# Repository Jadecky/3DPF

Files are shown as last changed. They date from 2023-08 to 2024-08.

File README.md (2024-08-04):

# Micron Filter

3DPF has now been retired, but V2 has been merged with the R1 Update of the Printers For Ants Micron+

This is the second itteration, that improves on some areas found from the V1 BETA

All V1 beta files and information are still available [here](https://github.com/Jadecky/3DPF/tree/main/Beta%201) for those that need them. 

## Changes iclude:
- New hex pattern for easier printing
- New Magnet system, consisting of M3x8 SHCS in the plenum, and a new push fit magnet holder in the catridge, to prevent magnets falling out due to the heat from the bed.
- Printablilty impovements
- Removed the 2x screws holding in the cartridge lid, and replaced with a chamfer to hold it in place

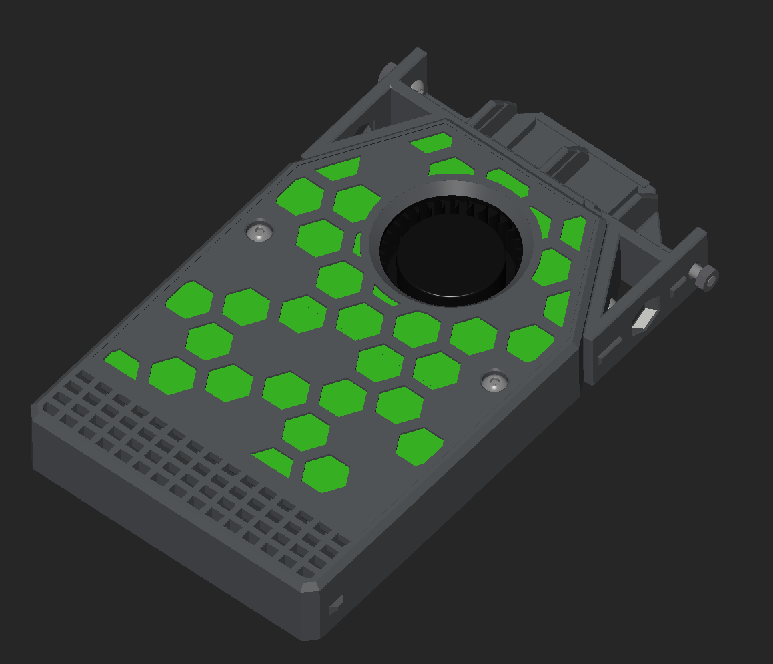
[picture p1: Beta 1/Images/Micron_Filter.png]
Micron_Filter

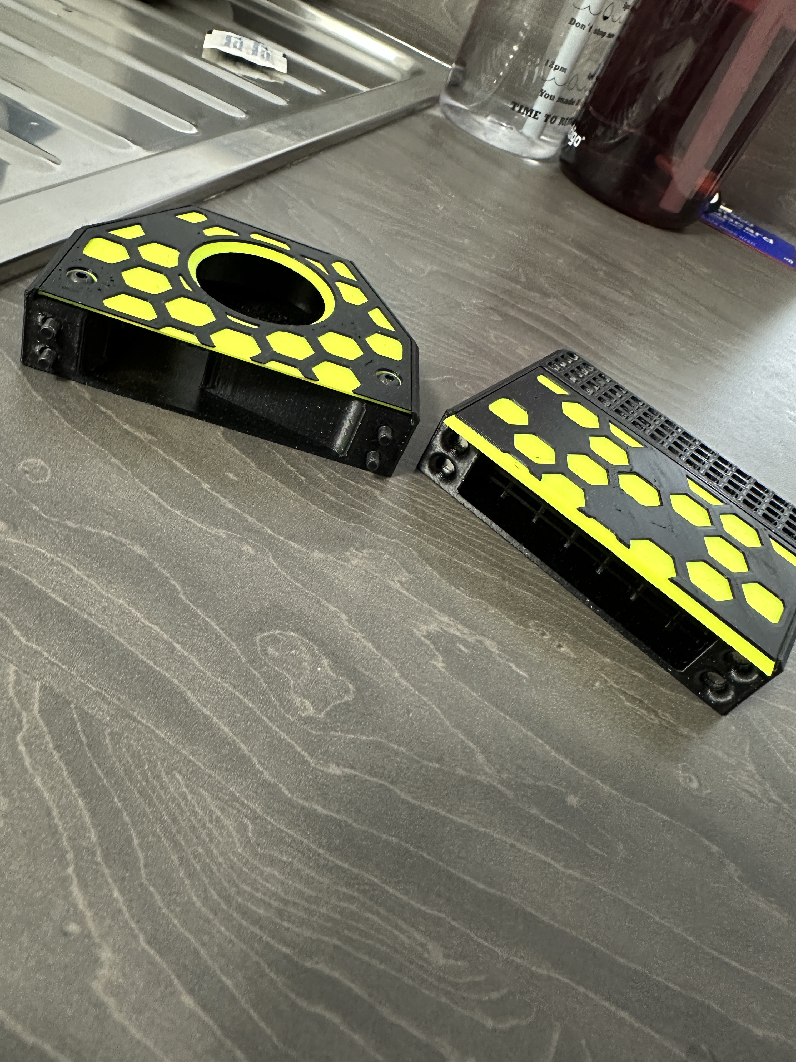
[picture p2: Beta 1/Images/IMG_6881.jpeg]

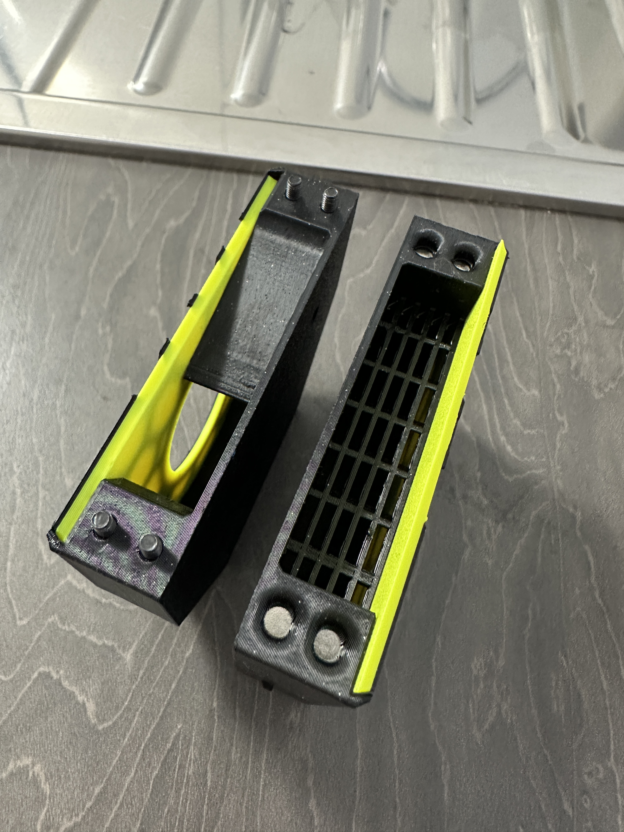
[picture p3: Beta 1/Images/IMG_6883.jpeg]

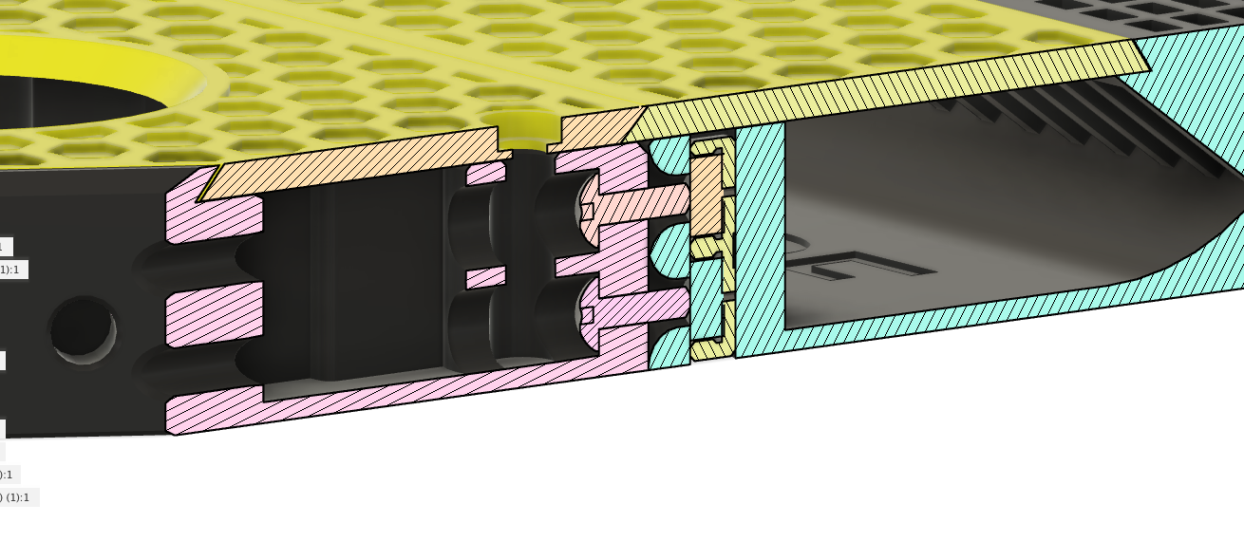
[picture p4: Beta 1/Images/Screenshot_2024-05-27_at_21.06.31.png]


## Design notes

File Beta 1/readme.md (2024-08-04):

## Legacy 3DPF V1 Information
3D Printing Filter, initially designed for PFA Micron+

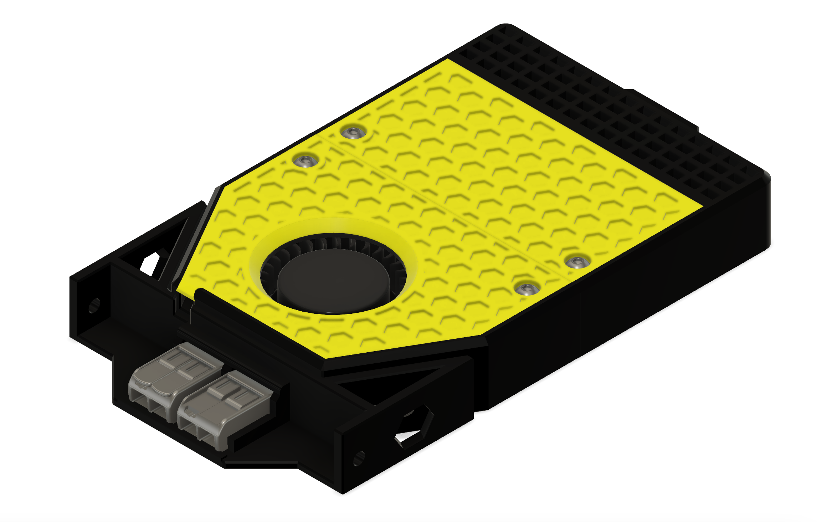
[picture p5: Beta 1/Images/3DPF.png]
3DPF


## Thank you
Equal amounts of credit should go to @staticanime for initial testing / feedback and ideas with this project. Thank you.

Also thanks to: 
- @Kyleisah for answering my 1000x CAD questions
- @.Corvid for the advice on the airflow adjustments from Test V3 to Test V4
- @clee & HartK for the naming convention style (borrowed from BFI)
- and obviously @HartK & the team for Micron+

## 3DPF
During my assembly of the Micron+ I noticed there wasn't a "made to fit" filter.

There are several very good options around:
- [The original Nevermore](https://github.com/nevermore3d/Nevermore_Micro) (Lots of good info on carbon filters on this page)
- [The ZeroFilter by @zruncho](https://github.com/zruncho3d/zerofilter)
- [The MF Nano by Maple Leaf Makers](https://github.com/MapleLeafMakers/MFNano)

These are all awesome, but are designed for other printers, so in comes the "3DPF" (3D Printing Filter):

(Name comes from me being a mechanic by trade, diesel cars have DPFs, 3D for obvious reasons, and it's pretty much a mixture of the 3x filters above)

This is my first proper CAD project, and so far it seems to be going well. It's nothing in comparison to some of the CAD geniuses in the community, but not a bad first attempt.

Current details as of Beta 1:

- 84mm (W) x 120mm (D) x 18.5mm (H)
- Uses a 5015 blower fan
- 6x3 magnets to attach the 2 bodies together
- Exhaust grill points upwards rather than to the door, with a taper to assist the air on the way out.

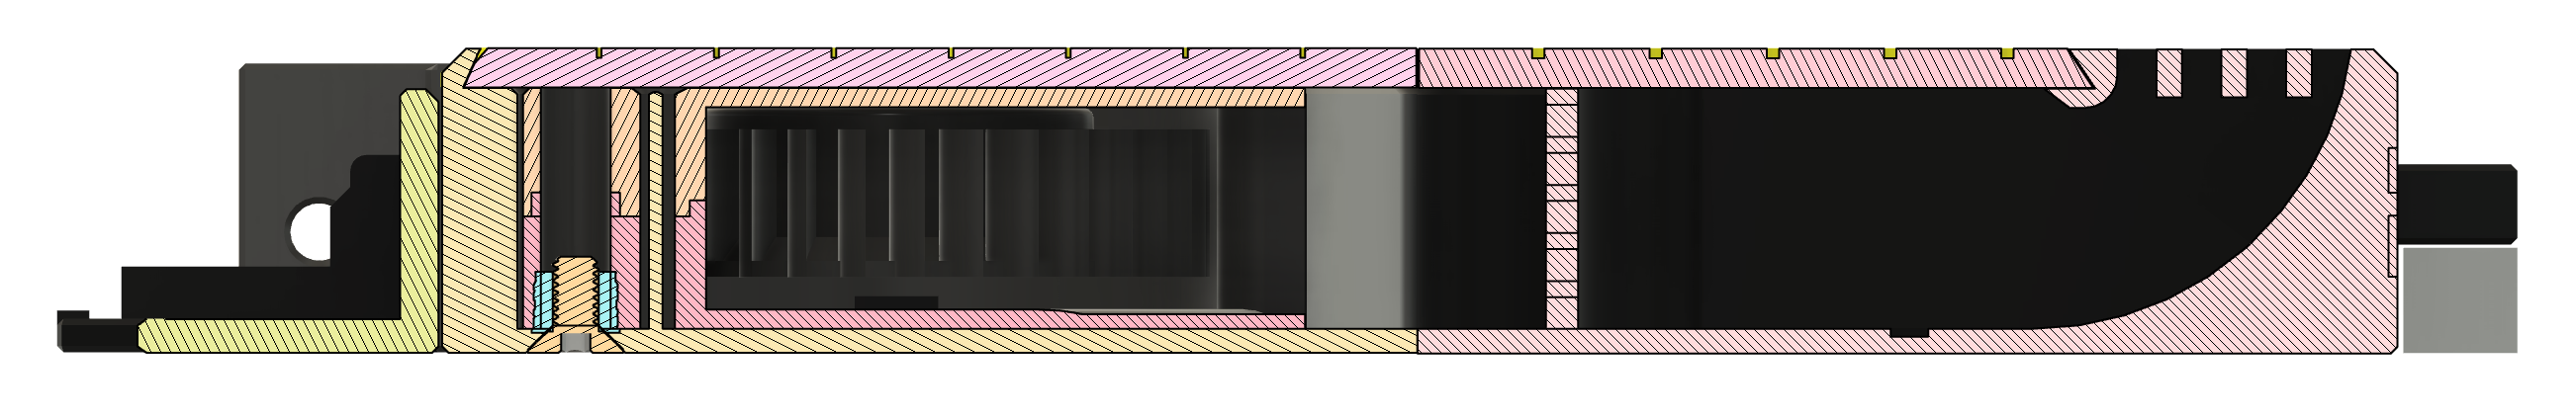
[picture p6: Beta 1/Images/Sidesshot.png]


- Current iteration has a grill with angled towers in an attempt to direct the air from the fan into the left of the cartridge.
- Wago mount / simple brackets that allow it to be slid into the extrusions from the front.
- Designed to fit under the Micron+ bed, much like the Nevermore does on a Voron V2

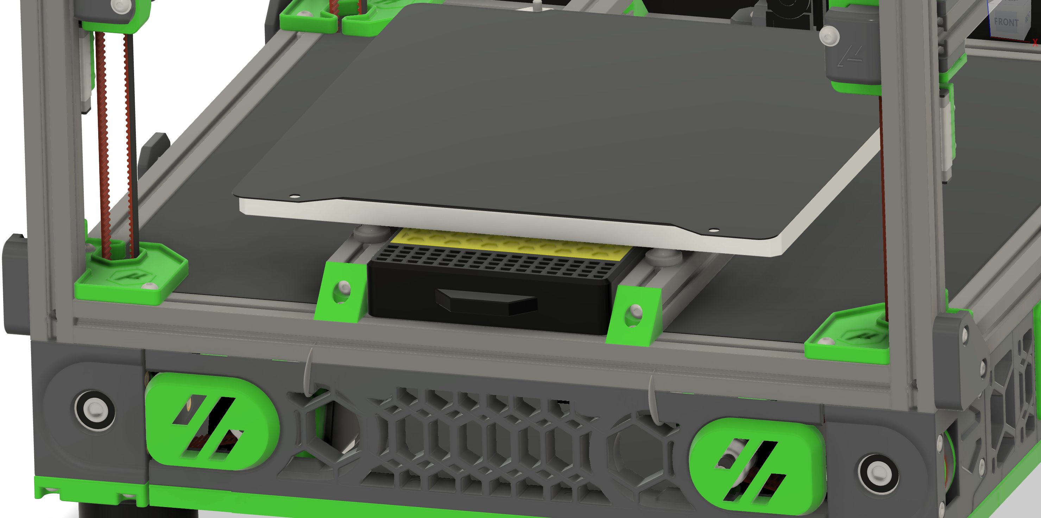
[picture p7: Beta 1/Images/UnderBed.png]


- 2x Cartridge options, one with a handle and one without.
- Handle variant includes built in, snap off supports

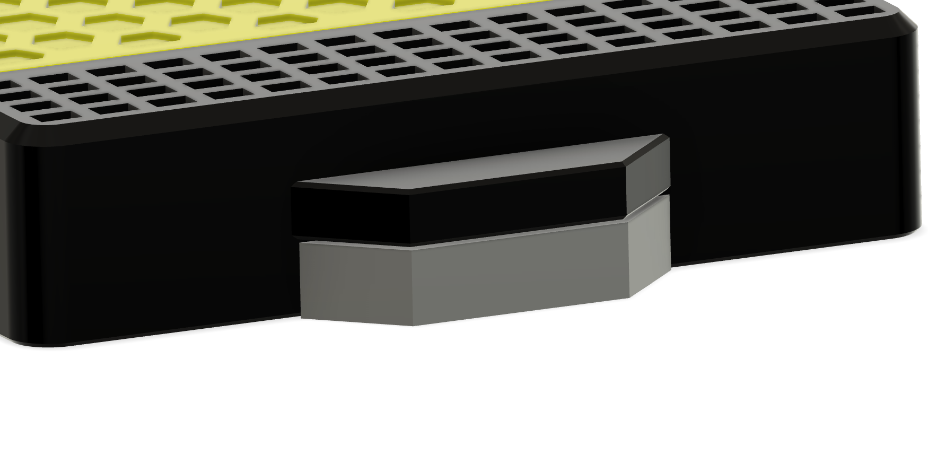
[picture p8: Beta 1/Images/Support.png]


## BOM
Qty |Part|Notes
---|----|---
8x|6x3 Magnets
8x|Voron Spec Brass Heatset Inserts|M3x5Dx4.5W
2x|M3x6 FHCS|M3x8 / M3x10 FHCS will also work
4x|M3x6 BHCS|M3x8 / M3x10 BHCS will also work for the cartridge and plenum lids
2x|M3x6 BHCS|To mount the brackets to the plenum
2x|M3x8 BHCS|To moount the brackets to the extrusions
1x|5015 Blower Fan
2x|Wago Connectors|221-412, Optional

## Printed Parts BOM
Qty|STL
---|---
1x|Plenum
1x|Cartridge [*]
1x|Cartridge_No_Text [*]
1x|Cartridge_Handle [*]
1x|Cartridge_Handle_No_Text [*]
1x|Plenum Lid
1x|Cartridge Lid
1x|Wago Mount [*]
2x|Compact Mounts (Left & Right) [*]
2x|Cartridge Removal Key

[*] Choose either/or
- "_No_Text" has no '3DPF' text on the front face of the cartridge.

## Assembly

- Insert 4x heatsets into the Cartridge and Plenum for the lid securing screws.

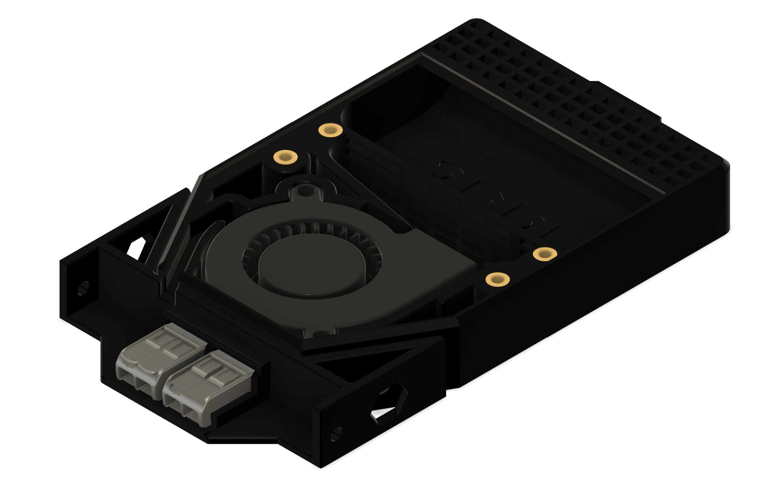
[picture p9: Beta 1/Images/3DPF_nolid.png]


- Insert 2x heatset inserts into the bottom of the screw tabs on the 5015 fan.

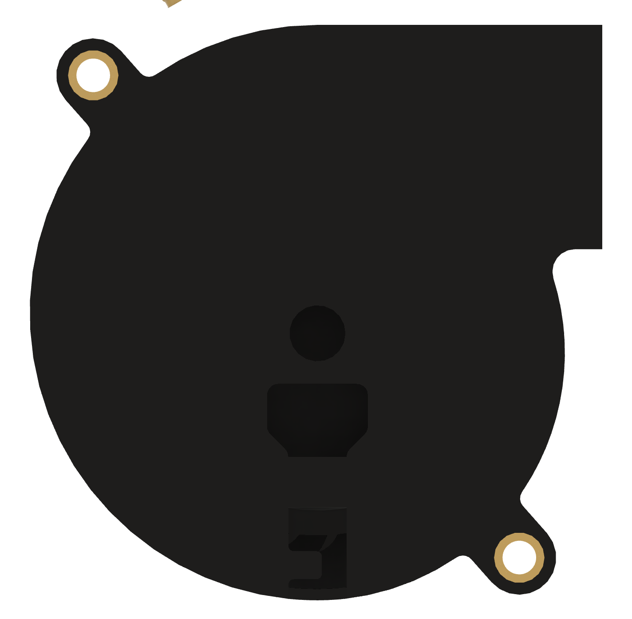
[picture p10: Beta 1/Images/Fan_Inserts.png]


- You may need to recess them 1-2 mm to allow the screws to sit correctly on the underside of the plenum.

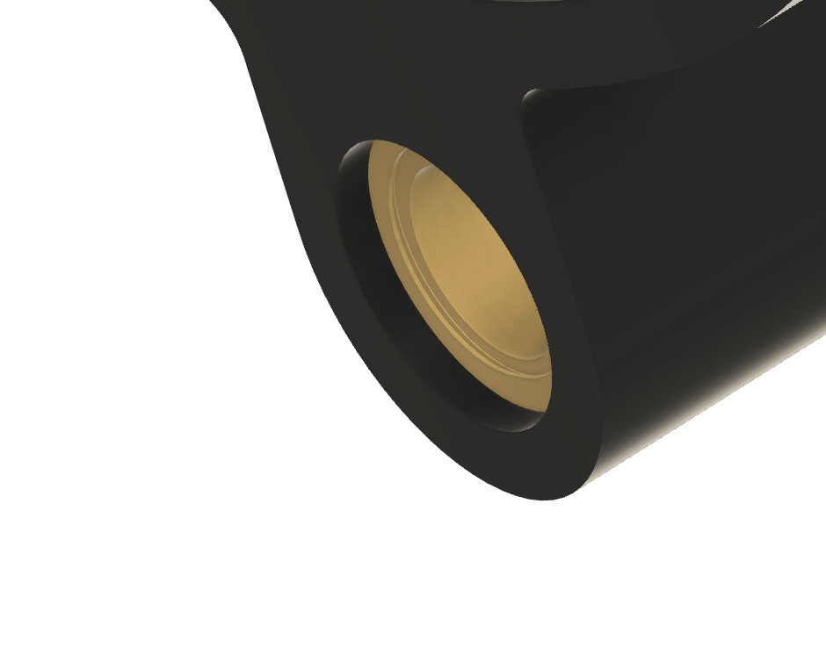
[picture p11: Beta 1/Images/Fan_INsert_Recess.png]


- Insert 2x heatsets into the 2x outside tapered edges of the plenum, where the mounting brackets will attatch. 

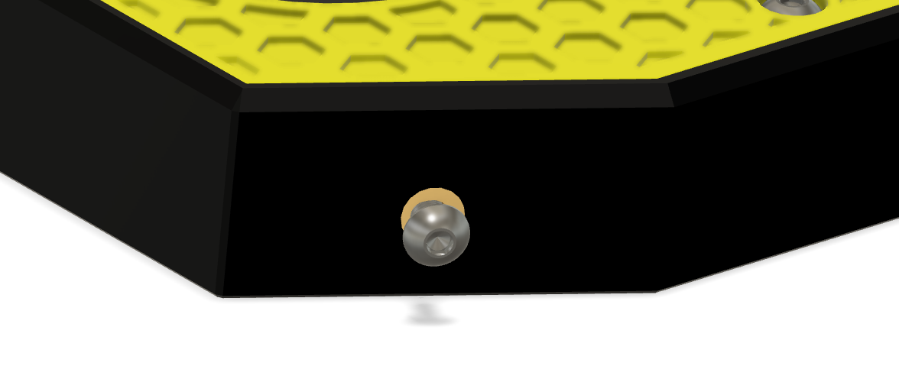
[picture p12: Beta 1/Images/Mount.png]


- Insert the fan into the plenum body routing the wire up the cable guide and out towards the back, and secure the fan with the 2x M3 FHCS from underneath the plenum.

- Attatch either the wago mount or 2x compact mounts to the plenum with M3x6 BHCS.

- Insert the 8x 6x3 Magnets into the provided holes on the mating faces of the cartridge & plenum.

- Fill cartridge with Carbon Pellets of your choosing.

- Slide the cartridge & plenum lids into place and secure with M3 BHCS.

## Cartridge Removal Key

If using the cartridge without a handle, it can be quite difficult to remove due to the 8x magnets. The removal key slots into the exhaust grill and allows you to easily pull forward on the cartridge.

You can use one in the centre, or 2x, with one on eiter outer edge.

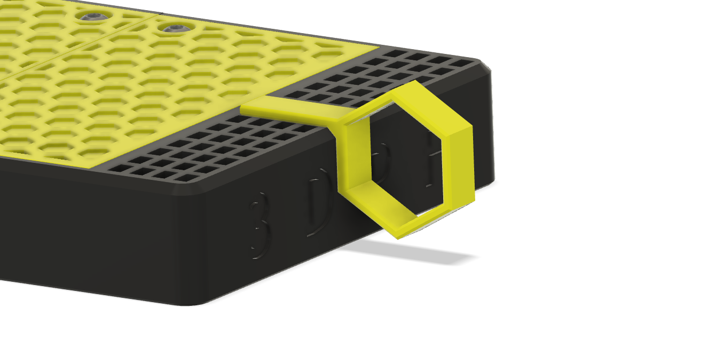
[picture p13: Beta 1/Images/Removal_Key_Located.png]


When printing, there are some tiny built in supports, shown in grey on the picture below.

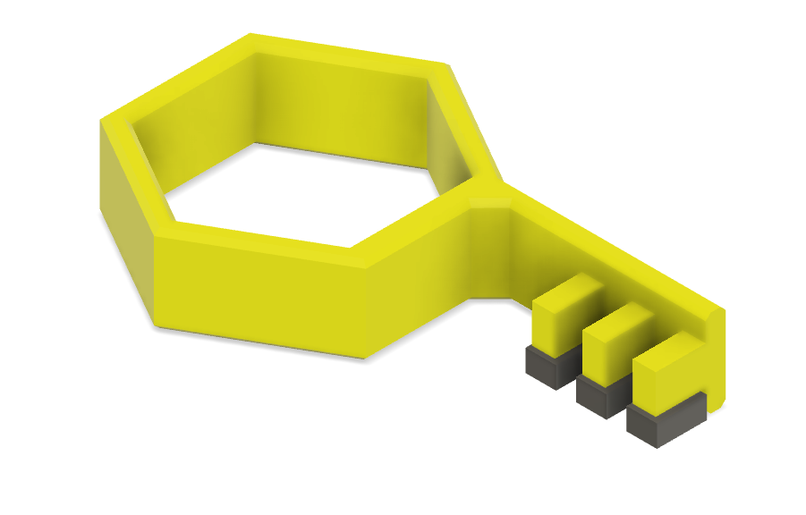
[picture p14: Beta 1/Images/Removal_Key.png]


## This filter is still in testing so any feedback/advice is much appreciated, please direct this to the [kyle_gb channel](https://discord.com/channels/825469421346226226/1132795892810907748) on the Doomcube discord.

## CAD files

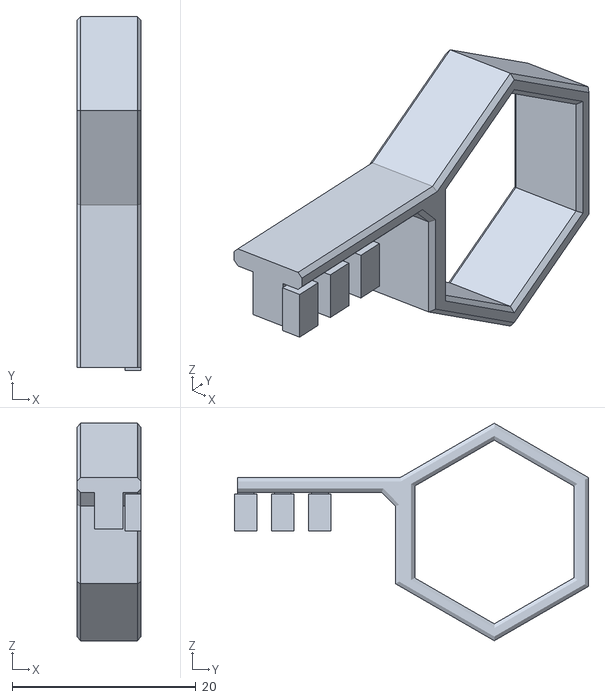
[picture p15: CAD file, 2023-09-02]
Beta 1/STLs/[a]_Cartridge_Removal_Key_x1.stl
7.00 x 38.6 x 23.7

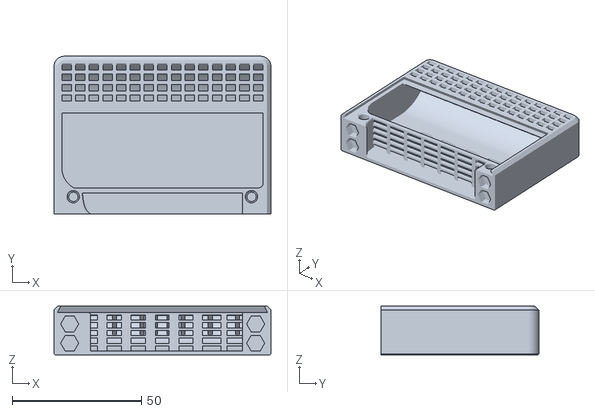
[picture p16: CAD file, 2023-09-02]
Beta 1/STLs/Cartridge.stl
84.0 x 61.0 x 19.0

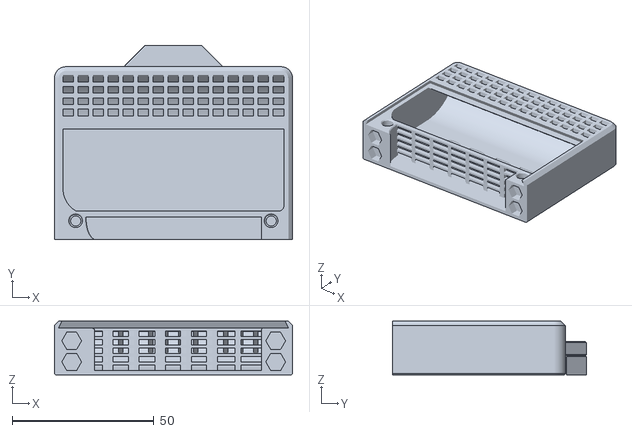
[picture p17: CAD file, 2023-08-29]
Beta 1/STLs/Cartridge_Handle_No_Text.stl
84.0 x 68.5 x 19.0

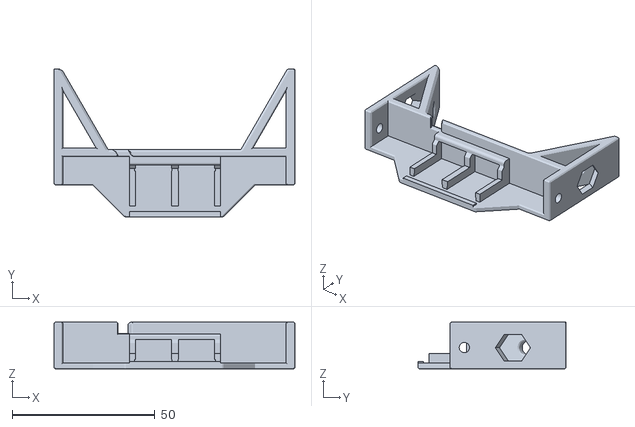
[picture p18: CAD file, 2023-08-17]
Beta 1/STLs/Wago_Mount.stl
84.5 x 52.0 x 16.4

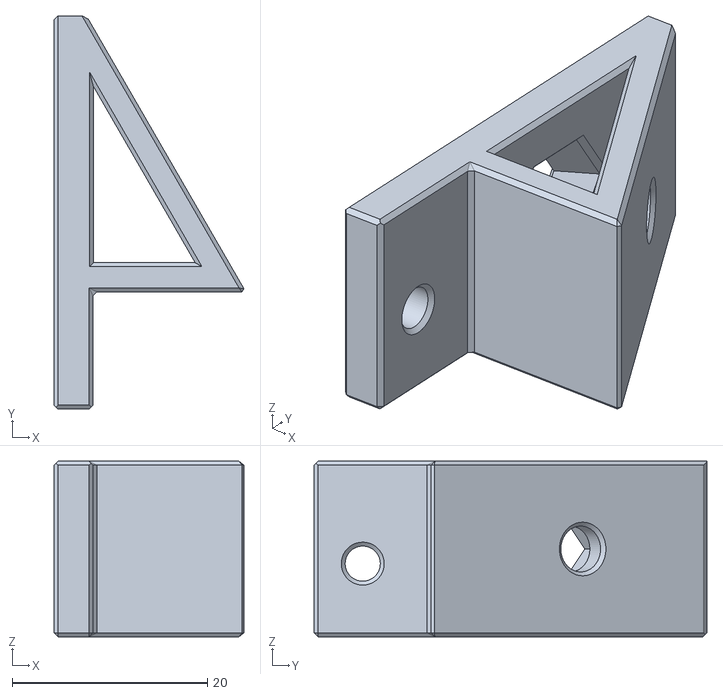
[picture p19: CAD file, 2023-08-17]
Beta 1/STLs/Compact Mount_L.stl
19.5 x 40.3 x 18.0

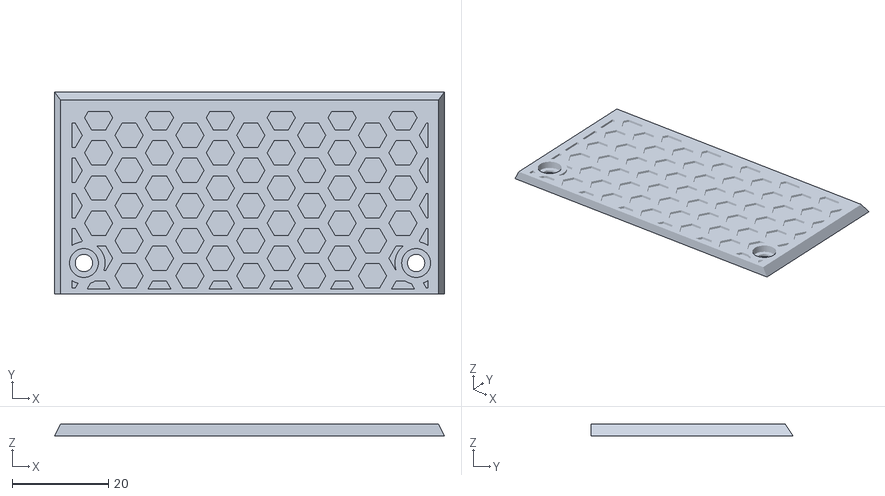
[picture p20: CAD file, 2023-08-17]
Beta 1/STLs/[a]_Cartridge_Lid.stl
81.0 x 42.0 x 2.45

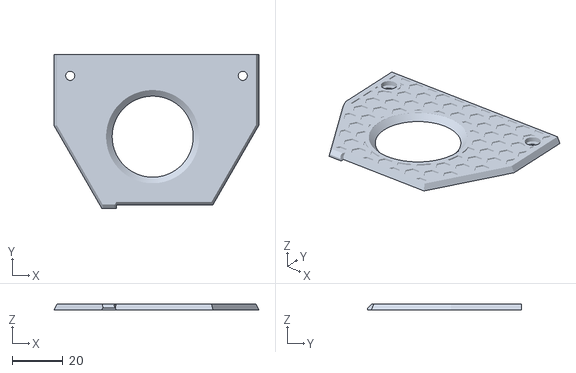
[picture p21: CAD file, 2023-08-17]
Beta 1/STLs/[a]_Plenum_Lid.stl
81.0 x 60.7 x 2.45

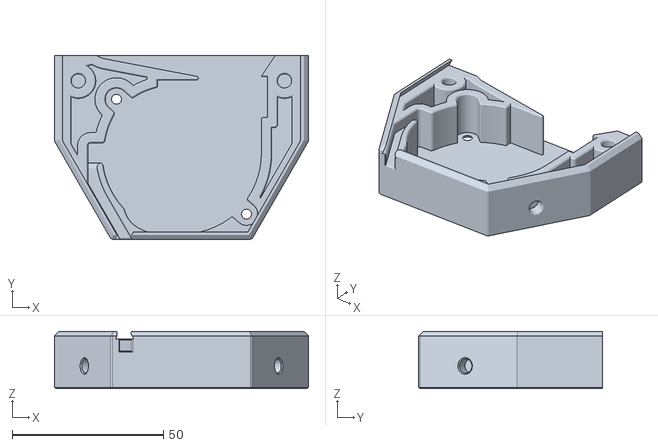
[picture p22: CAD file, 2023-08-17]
Beta 1/STLs/Plenum.stl
84.0 x 60.7 x 19.0

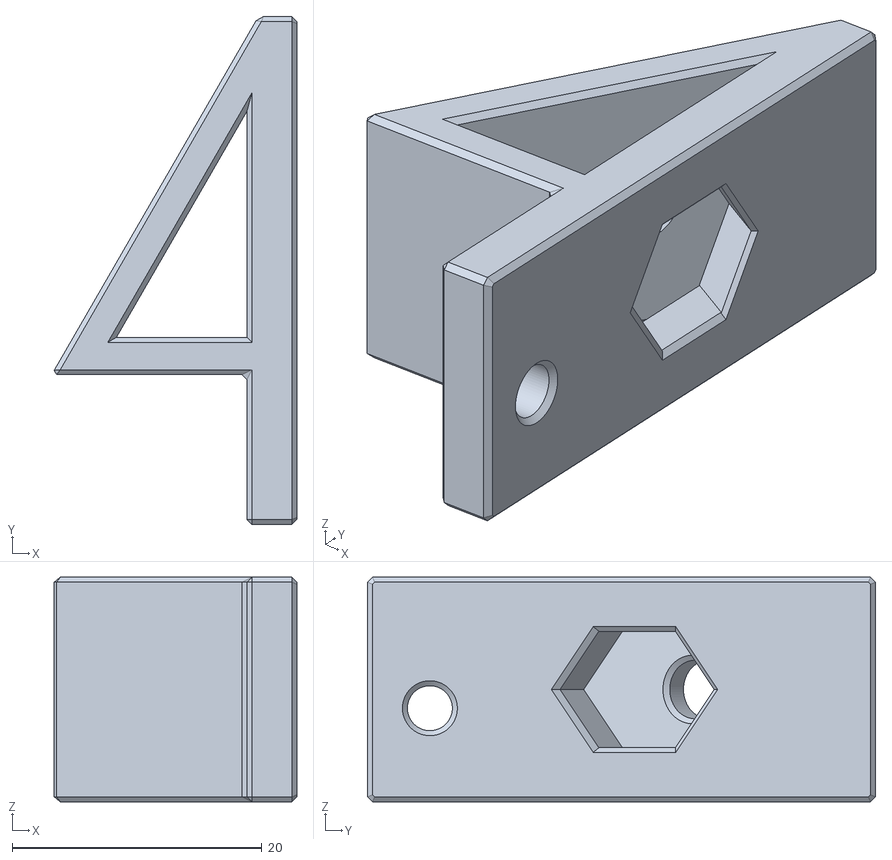
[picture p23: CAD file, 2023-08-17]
Beta 1/STLs/Compact Mount_R.stl
19.5 x 40.7 x 18.0

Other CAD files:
Beta 1/STLs/Cartridge_No Text.stl
Beta 1/STLs/Cartridge_Handle.stl

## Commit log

2023-08-17 Beta 1 Initial Upload
    [Cartridge.stl, Cartridge_Handle.stl, Compact Mount_L.stl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]
2023-08-17 Beta 1 - Upload
    [Cartridge.stl, Cartridge_Handle.stl, Compact Mount_L.stl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]
2023-08-29 Add Cartridge No Text
    [Cartridge_Handle_No_Text.stl, Cartridge_No Text.stl]
2023-09-02 Add Cartridge Removal Key
    [Cartridge.stl, [a]_Cartridge_Removal_Key_x1.stl]
2023-10-18 updated cad
2024-08-04 Upload photos of V2/Micron Filter
